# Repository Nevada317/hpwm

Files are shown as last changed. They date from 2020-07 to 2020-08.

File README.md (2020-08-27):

# Home PWM - Intelligent standalone LED light controller
**Home PWM** is PWM controller, designed to be used as LED light controller for ambient lightning using 12V led stripes and/or other 12V DC-powered lights.

*This project is not even Alpha-stage right now, so if you're interested in finished product only, don't waste your time building it.*

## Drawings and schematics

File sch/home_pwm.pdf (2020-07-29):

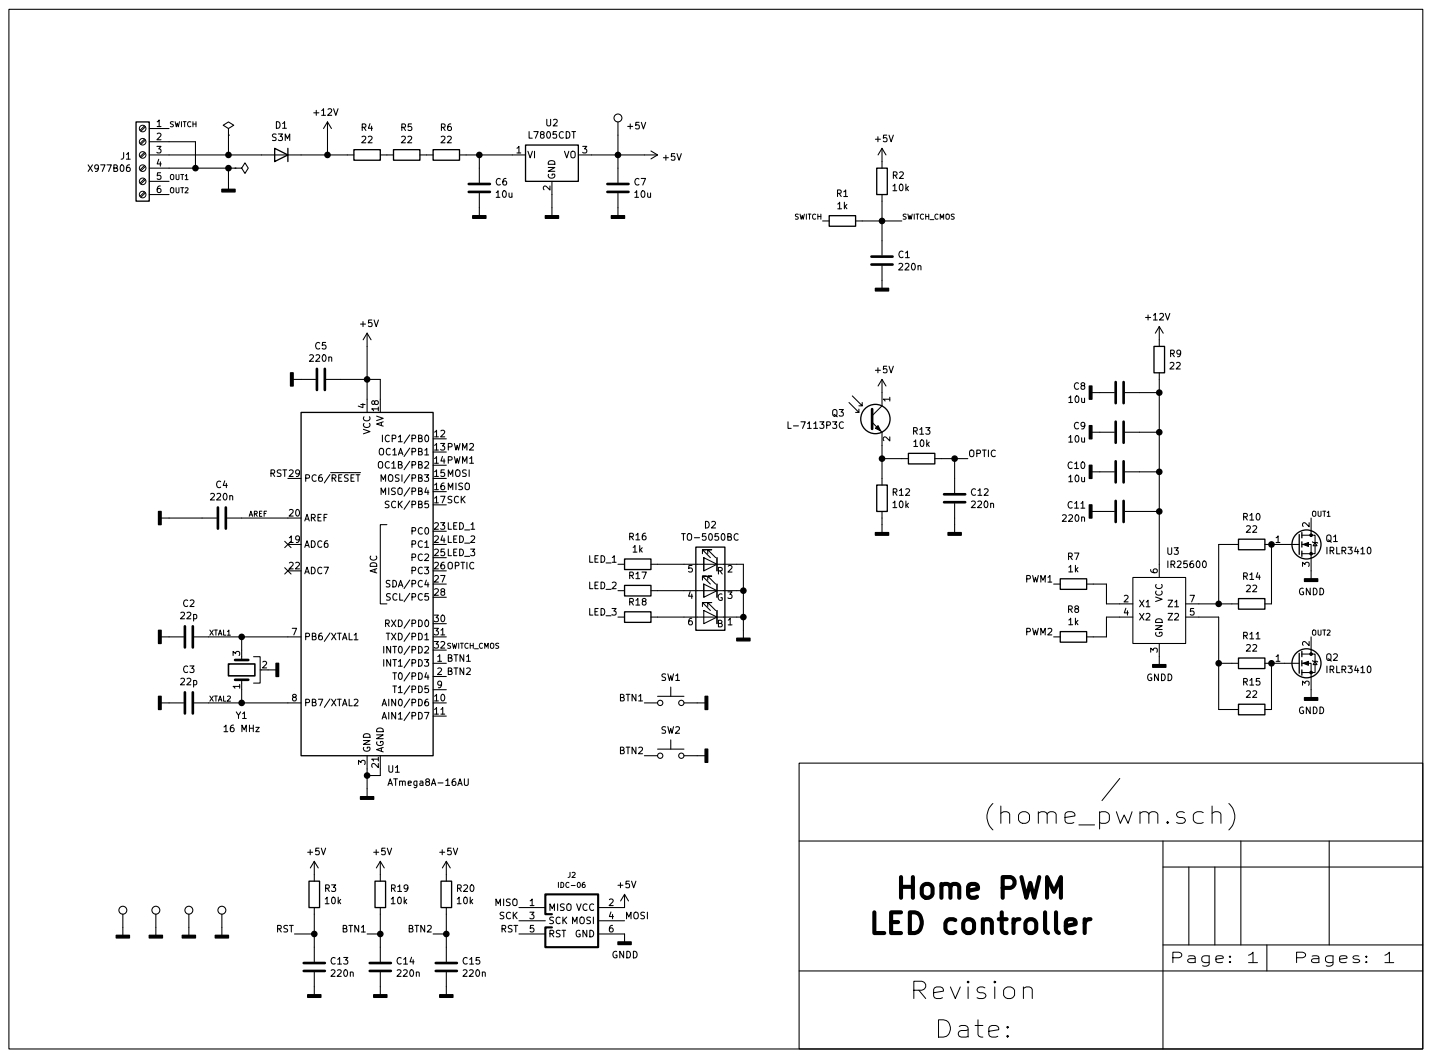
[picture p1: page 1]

Page: 1 | Pages: 1

Revision Date:

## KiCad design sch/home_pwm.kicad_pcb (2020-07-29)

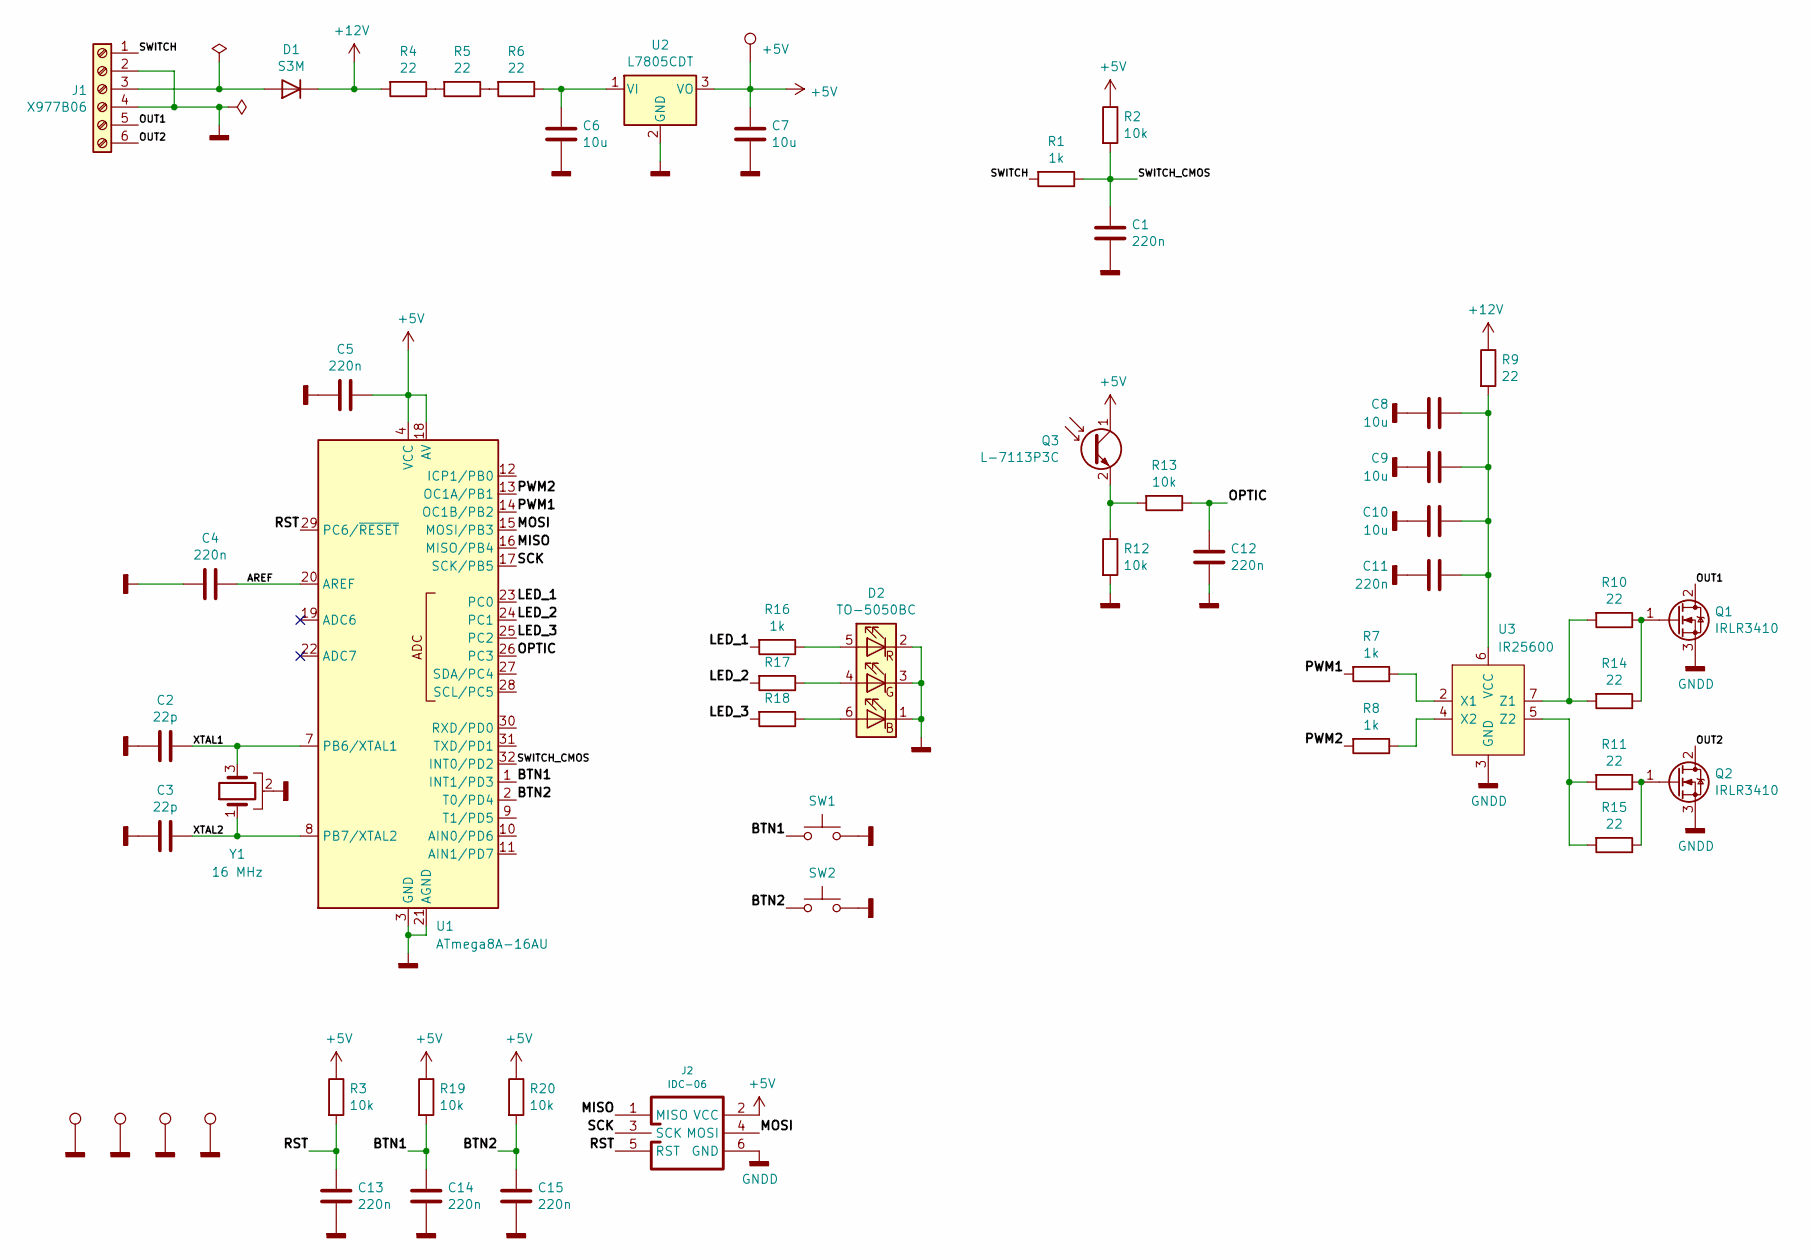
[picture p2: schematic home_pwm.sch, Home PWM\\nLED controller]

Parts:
C1, C4, C5, C11, C12, C13, C14, C15: 220n; C_0603
C2, C3: 22p; C_0603
C6, C7, C8, C9, C10: 10u; C_1206
D1: S3M; DO-214AB_SMC
D2: TO-5050BC; LED_RGB_5050-6
J1: X977B06; Terminal_X977B06
J2: IDC-06; IDC_Header_Straight_6pins
Q1, Q2: IRLR3410; D-PAK
Q3: L-7113P3C; LED_3.0mm_pin1-anode
R1, R7, R8, R16, R17, R18: 1k; R_0603
R2, R3, R12, R13, R19, R20: 10k; R_0603
R4, R5, R6, R9, R10, R11, R14, R15: 22; R_1206
SW1, SW2: SW; SW_PUSH_6mm
TP1, TP3: TestPoint; Screw_M3_6mm
TP2, TP4: TestPoint; Screw_M3_9mm
TP5: TestPoint; 1Pin
U1: ATmega8A-16AU; TQFP-32
U2: L7805CDT; D-PAK
U3: IR25600; SOP-8
Y1: 16 MHz; Crystal_HC-49SMD

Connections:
+5V: C5.1, C7.1, J2.2 (VCC), Q3.1 (C), R2.1, R3.1, R19.1, R20.1, TP5.1, U1.4 (VCC), U1.6 (VCC), U1.18 (AV), U2.3 (VO)
+12V: D1.1 (K), R4.2, R9.1
/AREF: C4.1, U1.20 (AREF)
/BTN1: C14.1, R19.2, SW1.1, U1.1 (INT1/PD3)
/BTN2: C15.1, R20.2, SW2.1, U1.2 (T0/PD4)
/LED_1: R16.2, U1.23 (PC0)
/LED_2: R17.2, U1.24 (PC1)
/LED_3: R18.2, U1.25 (PC2)
/MISO: J2.1 (MISO), U1.16 (MISO/PB4)
/MOSI: J2.4 (MOSI), U1.15 (MOSI/PB3)
/OPTIC: C12.1, R13.1, U1.26 (PC3)
/OUT1: J1.5, Q1.2 (D)
/OUT2: J1.6, Q2.2 (D)
/PWM1: R7.2, U1.14 (OC1B/PB2)
/PWM2: R8.2, U1.13 (OC1A/PB1)
/RST: C13.1, J2.5 (RST), R3.2, U1.29 (PC6/~RESET)
/SCK: J2.3 (SCK), U1.17 (SCK/PB5)
/SWITCH: J1.1, R1.2
/SWITCH_CMOS: C1.1, R1.1, R2.2, U1.32 (INT0/PD2)
/XTAL1: C2.1, U1.7 (PB6/XTAL1), Y1.3
/XTAL2: C3.1, U1.8 (PB7/XTAL2), Y1.1
GNDD: C1.2, C2.2, C3.2, C4.2, C5.2, C6.2, C7.2, C8.2, C9.2, C10.2, C11.2, C12.2, C13.2, C14.2, C15.2, D2.1 (BK), D2.2 (RK), D2.3 (GK), J1.2, J1.4, J2.6 (GND), Q1.3 (S), Q2.3 (S), R12.2, SW1.2, SW2.2, TP1.1, TP2.1, TP3.1, TP4.1, U1.3 (GND), U1.5 (GND), U1.21 (AGND), U2.2 (GND), U3.3 (GND), Y1.2
unnamed: C6.1, R6.1, U2.1 (VI)
unnamed: C8.1, C9.1, C10.1, C11.1, R9.2, U3.6 (VCC)
unnamed: D1.2 (A), J1.3
unnamed: D2.4 (GA), R17.1
unnamed: D2.5 (RA), R16.1
unnamed: D2.6 (BA), R18.1
unnamed: Q1.1 (G), R10.1, R14.1
unnamed: Q2.1 (G), R11.1, R15.1
unnamed: Q3.2 (E), R12.1, R13.2
unnamed: R4.1, R5.2
unnamed: R5.1, R6.2
unnamed: R7.1, U3.2 (X1)
unnamed: R8.1, U3.4 (X2)
unnamed: R10.2, R14.2, U3.7 (Z1)
unnamed: R11.2, R15.2, U3.5 (Z2)

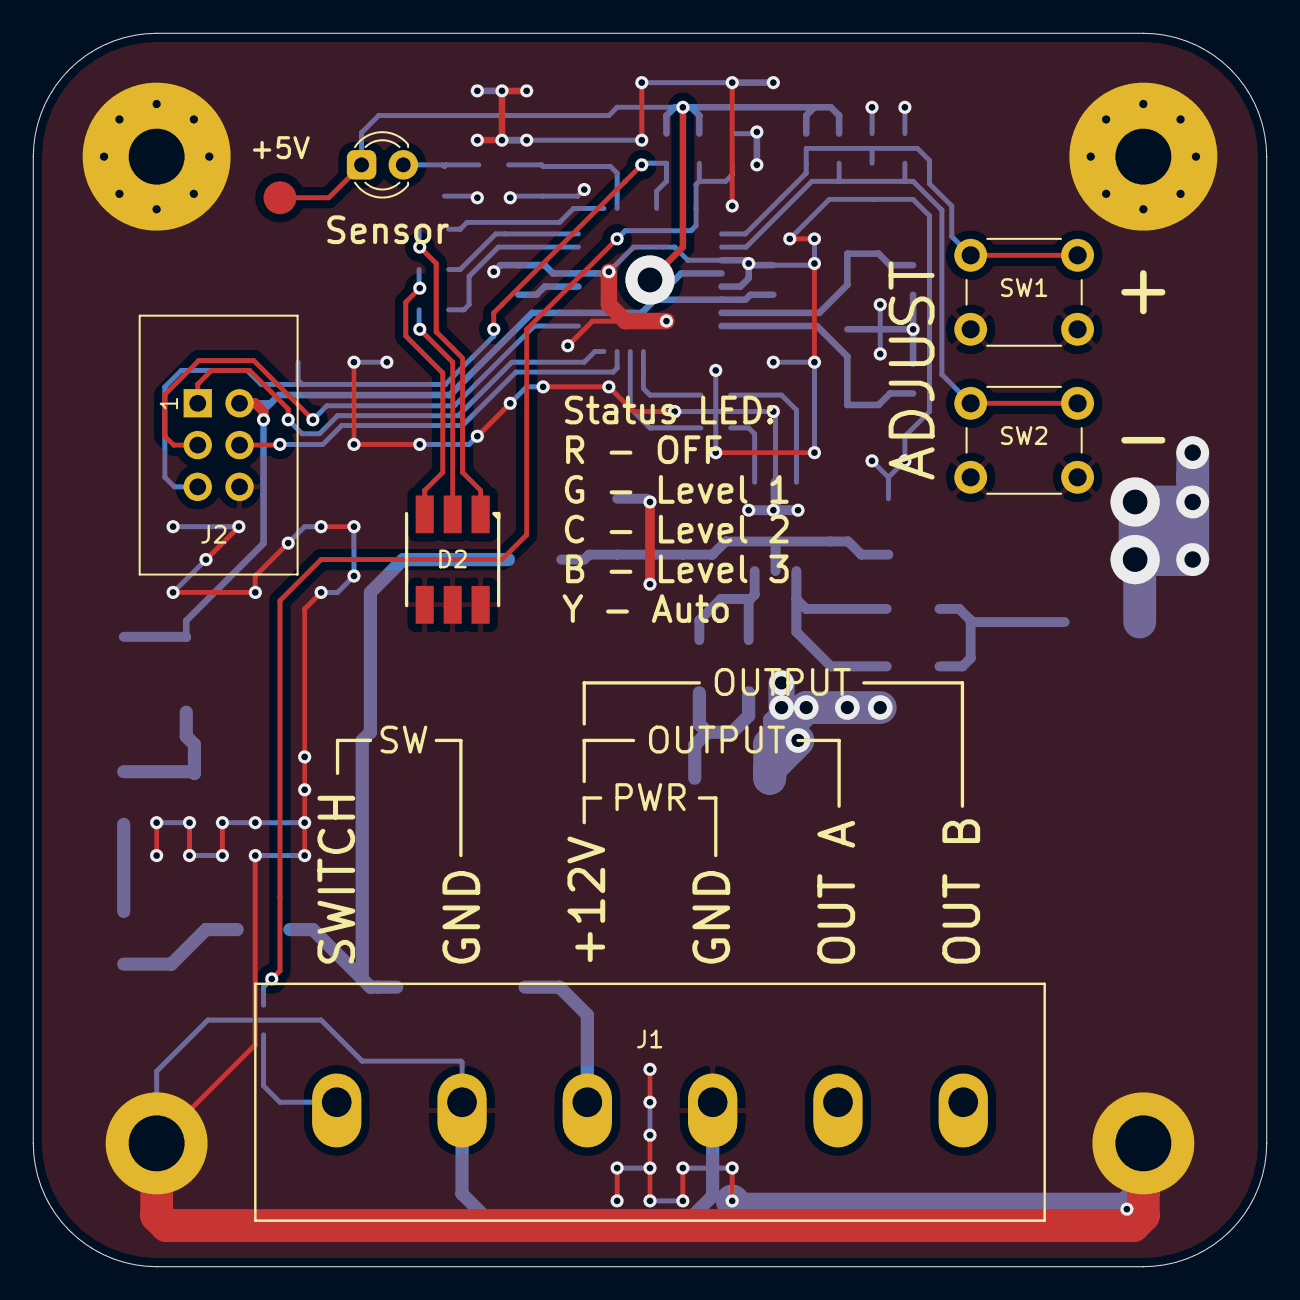
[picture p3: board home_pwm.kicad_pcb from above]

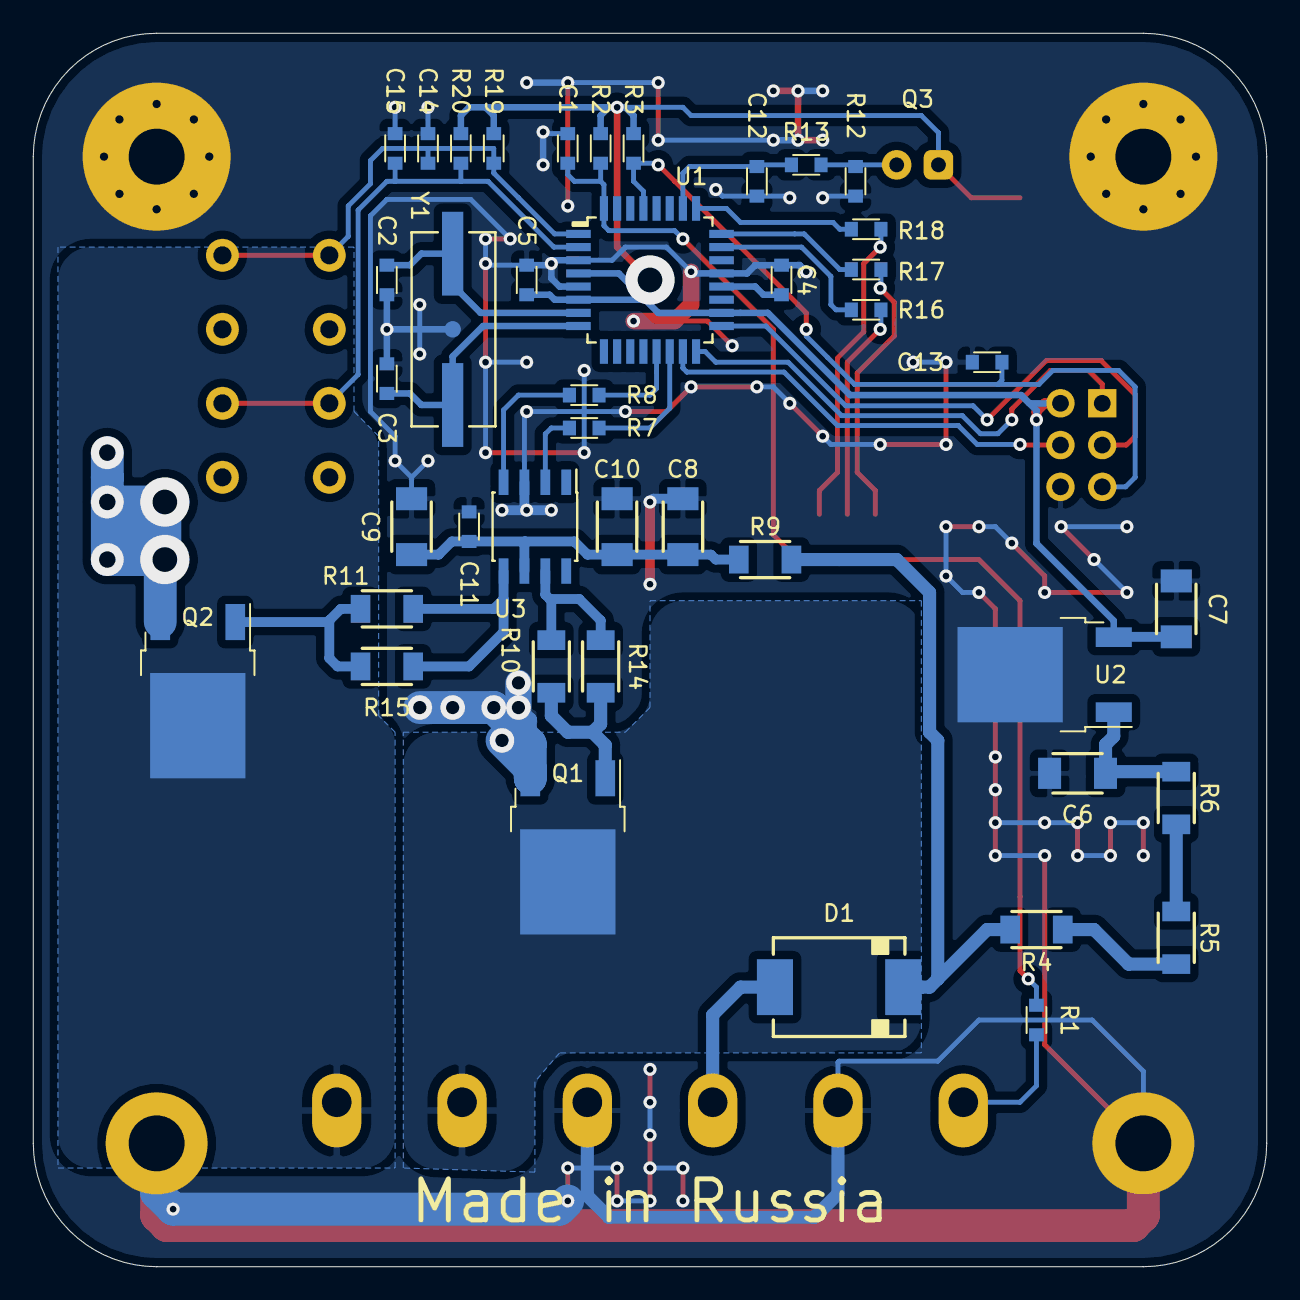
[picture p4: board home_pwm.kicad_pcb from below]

Board: 2 copper layers, 75.0 x 75.0 mm, 53 parts (42 on the bottom side), 37 nets.

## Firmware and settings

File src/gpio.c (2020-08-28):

#include "libs.h"

#define Button_Pin PIND
#define Button_Plus 3
#define Button_Minus 4
#define Button_Cooldown 4

static uint8_t* ptrBtnEdit = 0;

void GPIO_Init() {
	PORTB = 0b00111001;
	PORTC = 0b00110000;
	PORTD = 0b11111111;

	DDRB = 0b00000110;
	DDRC = 0b00000111;
	DDRD = 0b00000000;
}

void GPIO_Tick() {
	if (SYSTIMER_TO.TO_ButtonDelay != 0)
		return;
	uint8_t pins;
	pins = (uint8_t)~Button_Pin;
	pins &= ((1<<Button_Plus)|(1<<Button_Minus));
	if (pins == 0)
		return;
	if (pins == ((1<<Button_Plus)|(1<<Button_Minus)))
		return;
	// Here we are if valid button combination pressed
	if (ptrBtnEdit == 0)
		return;

	if (pins == (1<<Button_Plus)) {
		if (*ptrBtnEdit != 255){
			(*ptrBtnEdit)++;
			EEPROM_MarkDirty();
		}
	} else {
		if (*ptrBtnEdit != 0){
			(*ptrBtnEdit)--;
			EEPROM_MarkDirty();
		}
	}
	SYSTIMER_TO.TO_ButtonDelay = Button_Cooldown;
}

void GPIO_SetEditor(uint8_t* ptr) {
	ptrBtnEdit = ptr;
}

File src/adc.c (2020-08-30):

#include "libs.h"

static struct Avg {
	uint16_t Sum;
	uint8_t Count;
	uint16_t Valid;
} Averaging;

#define Tolerance 32

void ADC_Init() {
	ADMUX = (1<<REFS1) | (1<<REFS0) | (0<<ADLAR) | (0<<MUX3) | (0<<MUX2) | (1<<MUX1) | (1<<MUX0);
	ADCSRA = (1<<ADEN) | (1<<ADSC) | (1<<ADFR) | (1<<ADIF) | (1<<ADIE) | (1<<ADPS2) | (1<<ADPS1) | (1<<ADPS0);
}

ISR(ADC_vect) {
	if (CurrentMode != devMode_AUTO)
		return;

	uint16_t meas;
	meas = ADCL;
	meas = (meas & 0xFF) | (ADCH << 8);
	Averaging.Sum += meas;
	Averaging.Count++;

	if (Averaging.Count == 16) {
		Averaging.Count = 0;
		Averaging.Sum = 0;
	}

	if (Averaging.Count == 8) {
		Averaging.Valid = Averaging.Sum;

		uint16_t target = (*(rConfig+3) << 5) + (1 << 4);
		uint16_t diff;
		if (target >= Averaging.Valid)
			diff = target - Averaging.Valid;
		else
			diff = Averaging.Valid - target;

		uint8_t CurrentFader = PWM_GetFader();
		if (diff > Tolerance) {
			if ((target >= Averaging.Valid) && (CurrentFader < 255))
				CurrentFader++;
			if ((target < Averaging.Valid) && (CurrentFader > 0))
				CurrentFader--;
		}
		// If we have correct value already, we store current fader
		// value as fader target
		PWM_SetTarget(CurrentFader);
	}
// 	PWM_SetWGamma(255-ADCH);
}

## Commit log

2020-07-28 PCB draft
    [home_pwm.sch]
2020-07-29 PCB traced
    [home_pwm.kicad_pcb, home_pwm.sch]
2020-08-24 Power output tested
2020-08-25 ADCand PWM stubs added
2020-08-25 PWM should work
2020-08-25 PWM works
2020-08-26 ADC works
2020-08-27 Schematic moved to separate directory
    [home_pwm-B_Cu.gbr, home_pwm-B_Mask.gbr, home_pwm-B_Paste.gbr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]
2020-08-27 Old assembly removed
2020-08-27 Systimer implemented. Powerswitch now changes mode
2020-08-28 Plus/minus buttons implemented
2020-08-29 Buttons locked while lights are off
2020-08-29 Led brightness decreased while lights are off
2020-08-30 ADLAR cleared. Automatic level regulation works, but oscillation is noticable
    [adc.c]
